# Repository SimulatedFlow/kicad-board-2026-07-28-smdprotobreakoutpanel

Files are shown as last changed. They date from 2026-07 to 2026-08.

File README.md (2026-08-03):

# 2026-07-28-smdprotobreakoutpanel

<!-- SF-STORE-BLOCK:BEGIN -->
## 🛒 Source-available — see before you buy

This repository contains the **full design files** of a commercial hardware board. It is **source-available, not open source**: read it, evaluate it, then buy a license to use it. See **LICENSE.md (source-available, purchase required)**.

**Get it / Buy:**
- eBay store — all our boards and PCB art: https://www.ebay.de/usr/simula-9
- Merch shop (dev & gaming): https://simulatedflow.myspreadshop.de
- Merch shop (Synthetica / EDM): https://synthetica.myspreadshop.de
- Direct / invoice (Simulated Flow UG): simulatedflow@gmail.com

_This board has no eBay item number of its own listed here — the store link above holds all current listings._

### 📬 **Free Board Documentation & Firmware Pack**

Schematics, BOMs and example-firmware docs for our STM32 carrier boards. Get it by joining the newsletter — plus a heads-up when something new ships. Double opt-in, unsubscribe in one click, no address sharing.

👉 **[Get the free pack](https://simulatedflow.teufel-engineering.com/newsletter/hardware/?q=gh)**

_© 2026 Simulated Flow UG. All rights reserved._
<!-- SF-STORE-BLOCK:END -->

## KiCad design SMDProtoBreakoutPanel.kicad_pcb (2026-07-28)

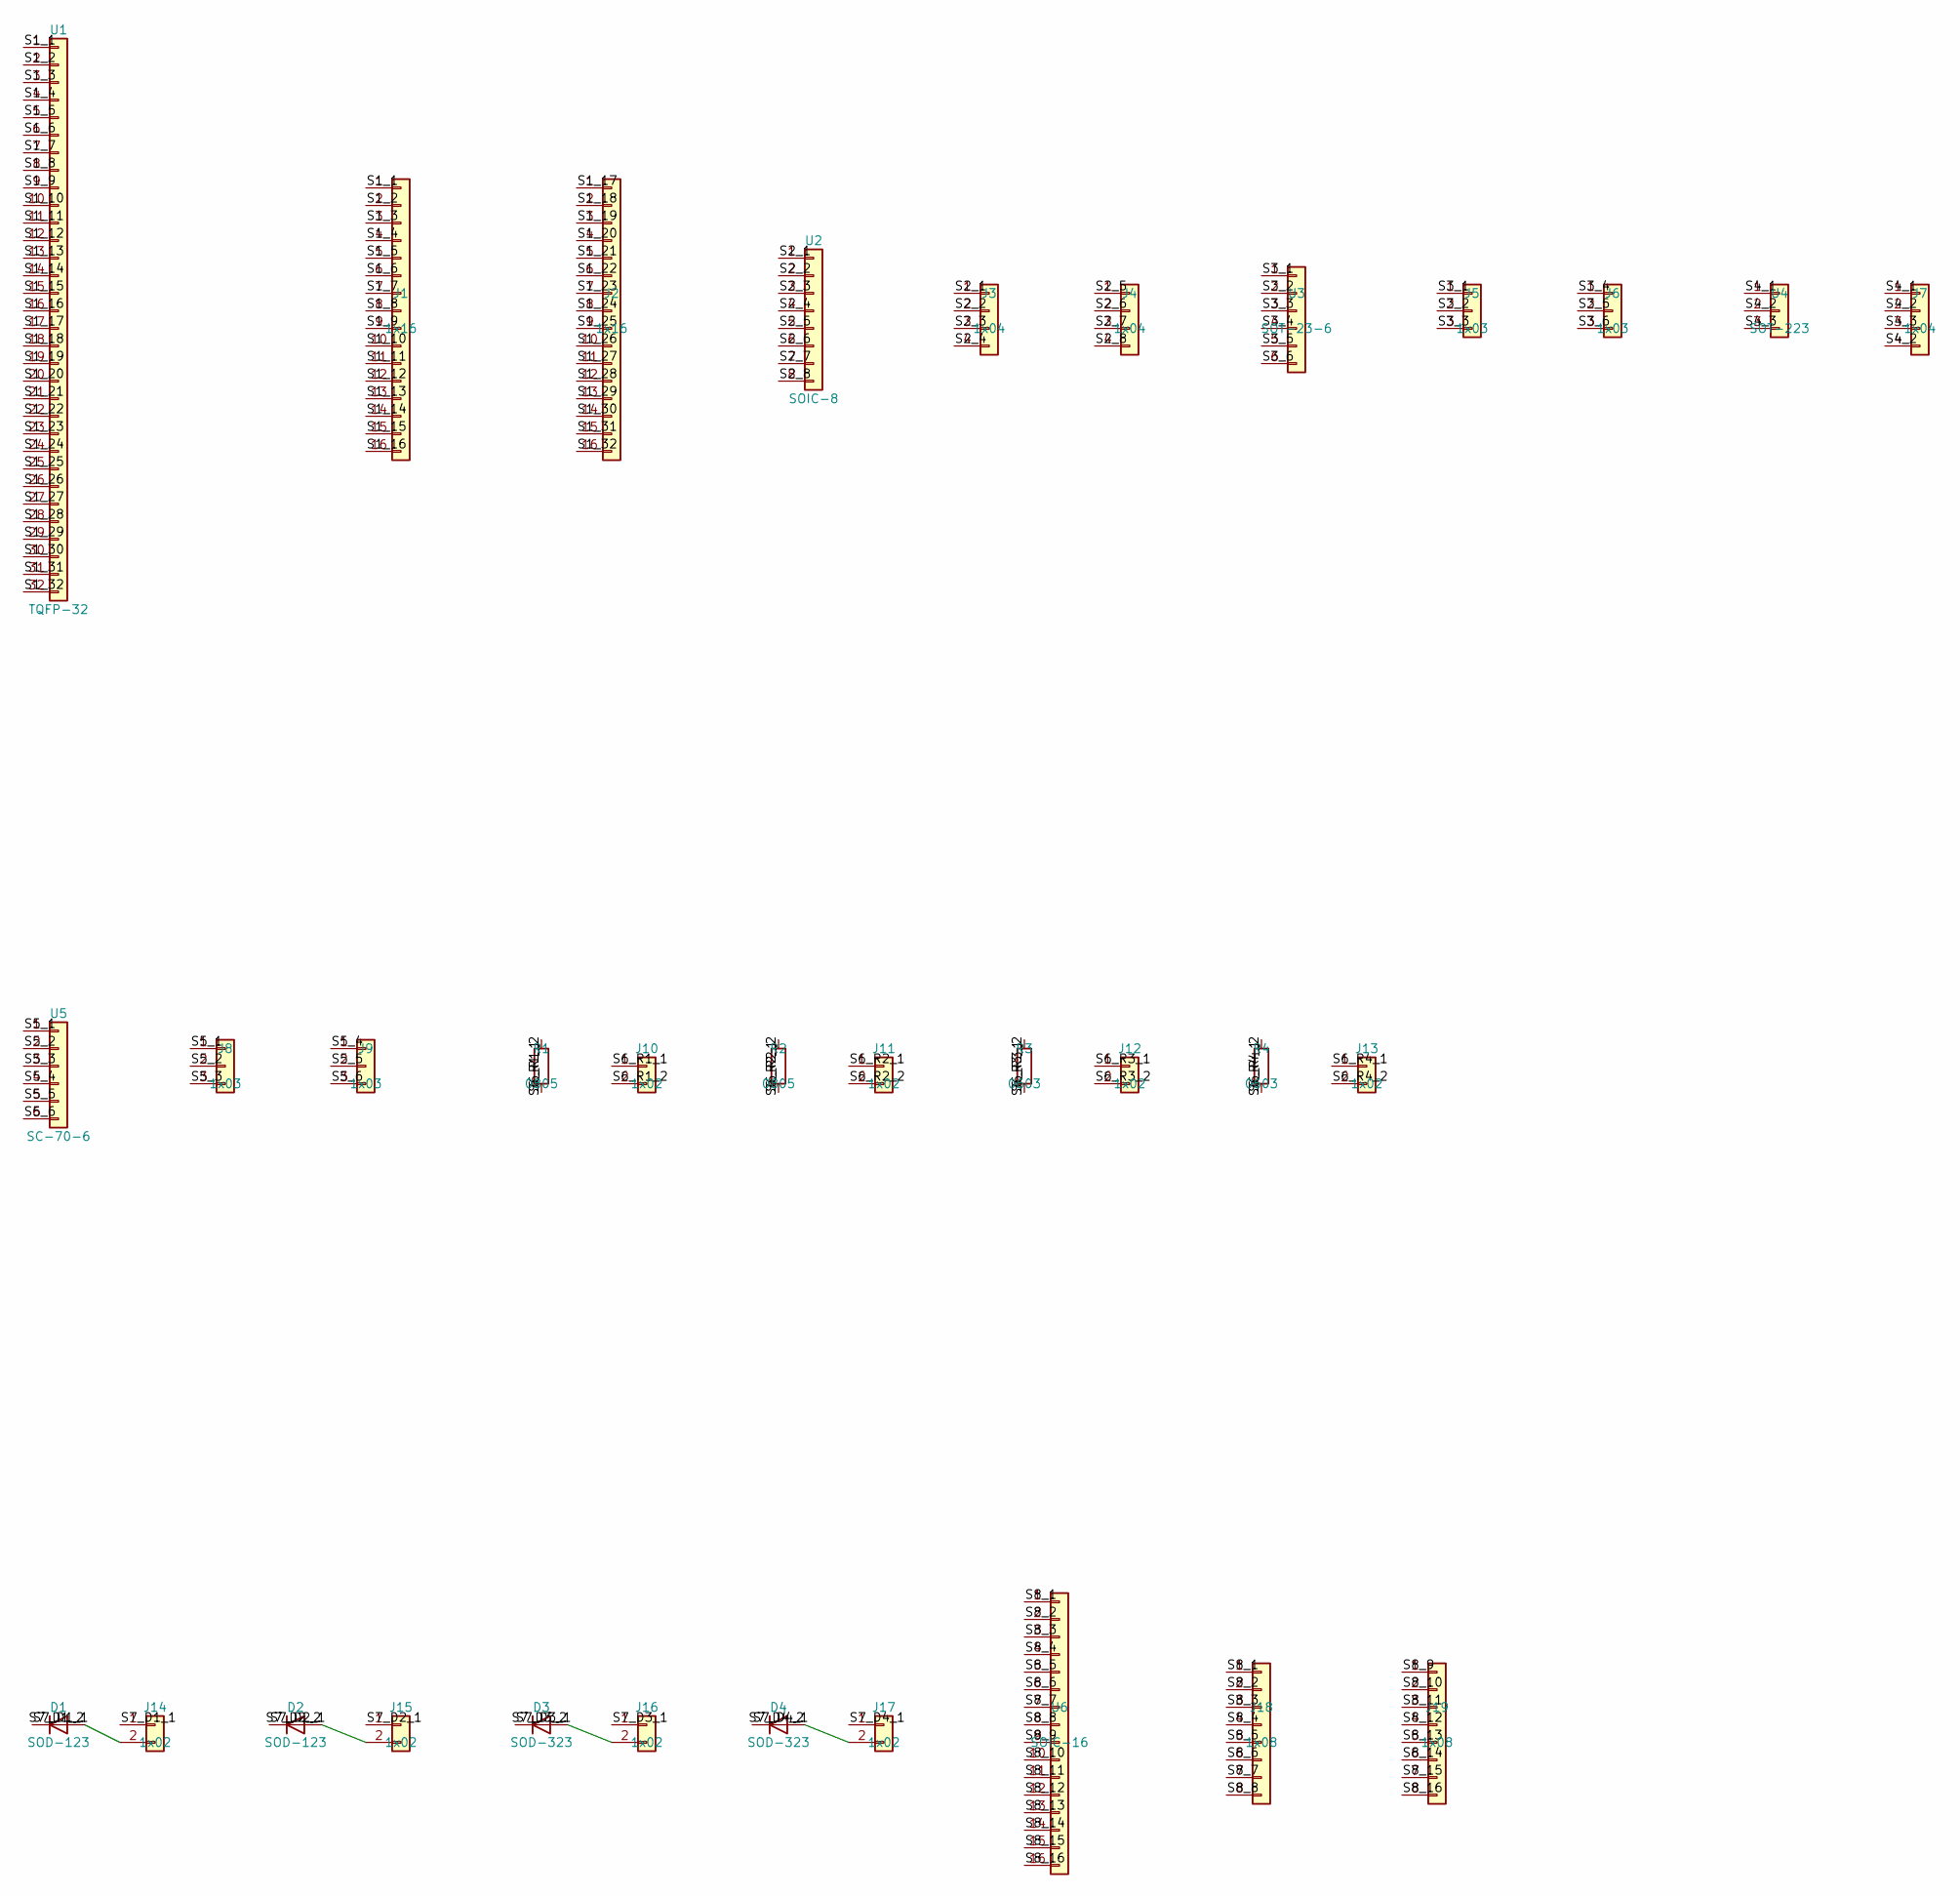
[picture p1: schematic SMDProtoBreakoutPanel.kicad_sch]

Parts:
D1, D2: SOD-123; D_SOD-123
D3, D4: SOD-323; D_SOD-323_HandSoldering
J1, J2: 1x16; PinHeader_1x16_P2.54mm_Vertical
J3, J4, J7: 1x04; PinHeader_1x04_P2.54mm_Vertical
J5, J6, J8, J9: 1x03; PinHeader_1x03_P2.54mm_Vertical
J10, J11, J12, J13, J14, J15, J16, J17: 1x02; PinHeader_1x02_P2.54mm_Vertical
J18, J19: 1x08; PinHeader_1x08_P2.54mm_Vertical
R1, R2: 0805; R_0805_2012Metric_Pad1.20x1.40mm_HandSolder
R3, R4: 0603; R_0603_1608Metric_Pad0.98x0.95mm_HandSolder
U1: TQFP-32; TQFP-32_7x7mm_P0.8mm
U2: SOIC-8; SOIC-8_3.9x4.9mm_P1.27mm
U3: SOT-23-6; SOT-23-6_Handsoldering
U4: SOT-223; SOT-223-3_TabPin2
U5: SC-70-6; SOT-363_SC-70-6
U6: SOIC-16; SOIC-16_3.9x9.9mm_P1.27mm

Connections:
S1_1: J1.1, U1.1
S1_2: J1.2, U1.2
S1_3: J1.3, U1.3
S1_4: J1.4, U1.4
S1_5: J1.5, U1.5
S1_6: J1.6, U1.6
S1_7: J1.7, U1.7
S1_8: J1.8, U1.8
S1_9: J1.9, U1.9
S1_10: J1.10, U1.10
S1_11: J1.11, U1.11
S1_12: J1.12, U1.12
S1_13: J1.13, U1.13
S1_14: J1.14, U1.14
S1_15: J1.15, U1.15
S1_16: J1.16, U1.16
S1_17: J2.1, U1.17
S1_18: J2.2, U1.18
S1_19: J2.3, U1.19
S1_20: J2.4, U1.20
S1_21: J2.5, U1.21
S1_22: J2.6, U1.22
S1_23: J2.7, U1.23
S1_24: J2.8, U1.24
S1_25: J2.9, U1.25
S1_26: J2.10, U1.26
S1_27: J2.11, U1.27
S1_28: J2.12, U1.28
S1_29: J2.13, U1.29
S1_30: J2.14, U1.30
S1_31: J2.15, U1.31
S1_32: J2.16, U1.32
S2_1: J3.1, U2.1
S2_2: J3.2, U2.2
S2_3: J3.3, U2.3
S2_4: J3.4, U2.4
S2_5: J4.1, U2.5
S2_6: J4.2, U2.6
S2_7: J4.3, U2.7
S2_8: J4.4, U2.8
S3_1: J5.1, U3.1
S3_2: J5.2, U3.2
S3_3: J5.3, U3.3
S3_4: J6.1, U3.4
S3_5: J6.2, U3.5
S3_6: J6.3, U3.6
S4_1: J7.1, U4.1
S4_2: J7.2, J7.4, U4.2
S4_3: J7.3, U4.3
S5_1: J8.1, U5.1
S5_2: J8.2, U5.2
S5_3: J8.3, U5.3
S5_4: J9.1, U5.4
S5_5: J9.2, U5.5
S5_6: J9.3, U5.6
S6_R1_1: J10.1, R1.1
S6_R1_2: J10.2, R1.2
S6_R2_1: J11.1, R2.1
S6_R2_2: J11.2, R2.2
S6_R3_1: J12.1, R3.1
S6_R3_2: J12.2, R3.2
S6_R4_1: J13.1, R4.1
S6_R4_2: J13.2, R4.2
S7_D1_1: D1.1 (K), J14.1
S7_D1_2: D1.2 (A), J14.2
S7_D2_1: D2.1 (K), J15.1
S7_D2_2: D2.2 (A), J15.2
S7_D3_1: D3.1 (K), J16.1
S7_D3_2: D3.2 (A), J16.2
S7_D4_1: D4.1 (K), J17.1
S7_D4_2: D4.2 (A), J17.2
S8_1: J18.1, U6.1
S8_2: J18.2, U6.2
S8_3: J18.3, U6.3
S8_4: J18.4, U6.4
S8_5: J18.5, U6.5
S8_6: J18.6, U6.6
S8_7: J18.7, U6.7
S8_8: J18.8, U6.8
S8_9: J19.1, U6.9
S8_10: J19.2, U6.10
S8_11: J19.3, U6.11
S8_12: J19.4, U6.12
S8_13: J19.5, U6.13
S8_14: J19.6, U6.14
S8_15: J19.7, U6.15
S8_16: J19.8, U6.16

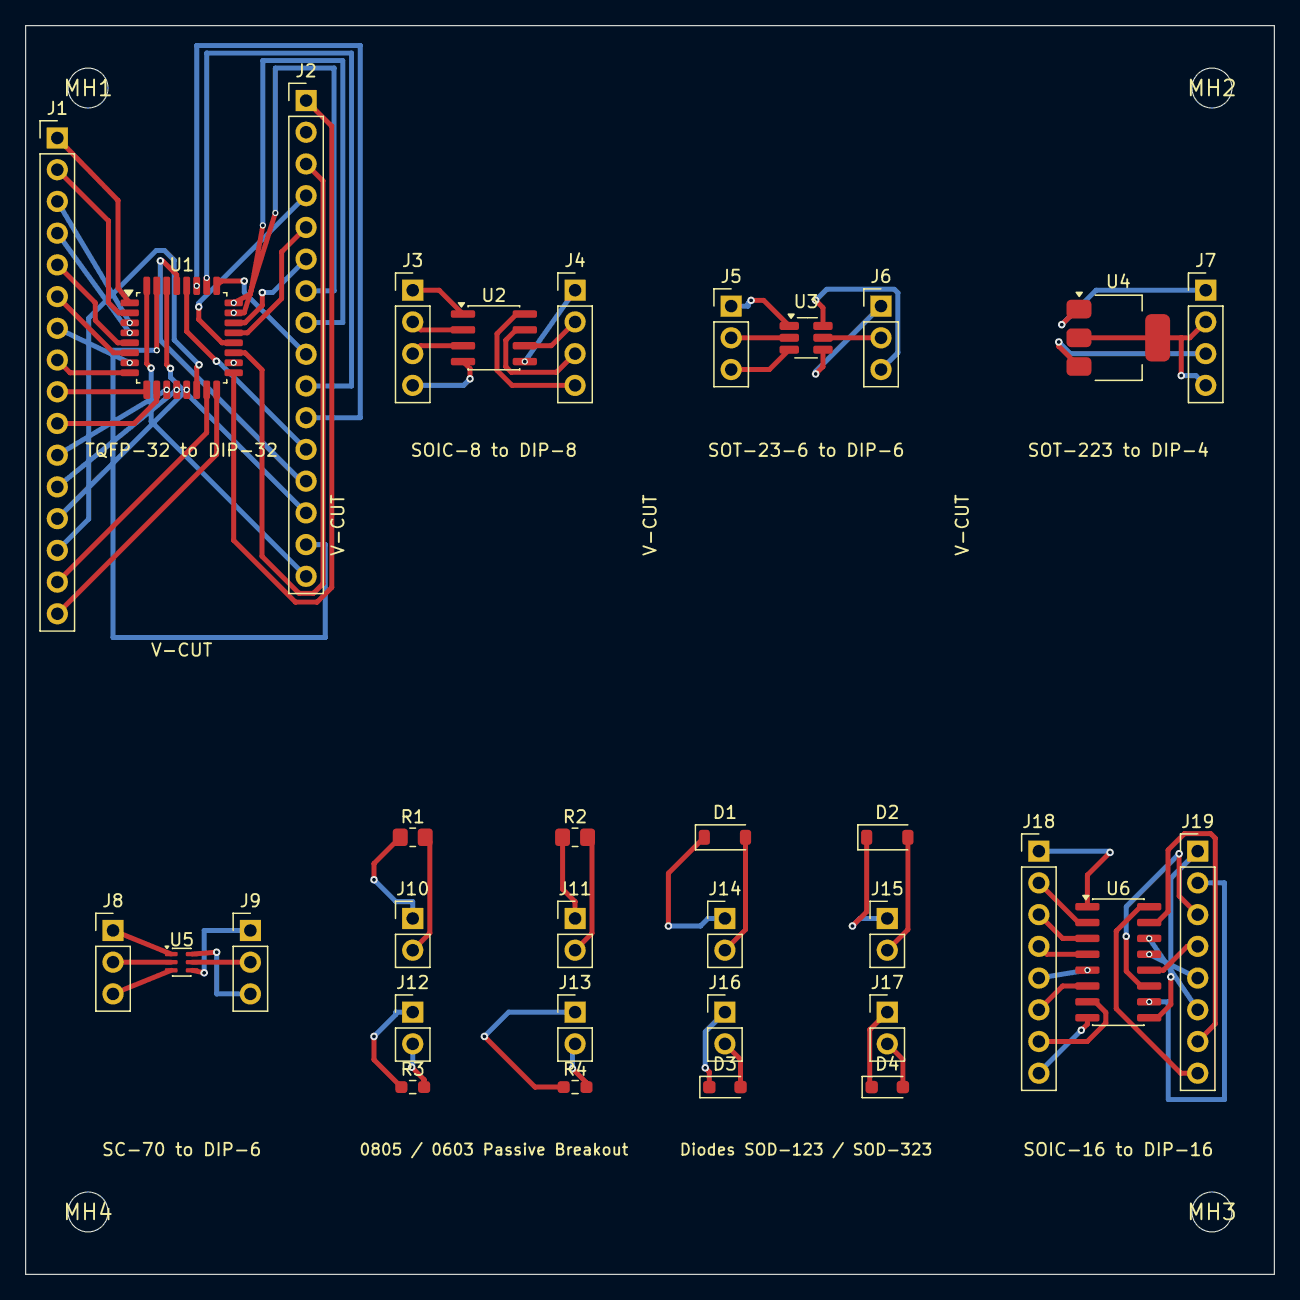
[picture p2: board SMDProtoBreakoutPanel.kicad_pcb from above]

Board: 4 copper layers, 100.0 x 100.0 mm, 37 parts (0 on the bottom side), 87 nets.

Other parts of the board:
MH1, MH2, MH3, MH4: MountingHole_3.2mm

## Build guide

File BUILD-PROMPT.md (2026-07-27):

```json
{
  "board_name": "SMDProtoBreakoutPanel",
  "one_liner": "Ein universelles, per V-Cut ausbrechbares SMD-zu-THT Adapterpanel für 8 gängige SMD-Footprints auf 2,54mm-Breadboard-Raster.",
  "market_gap": "Bastler scheuen oft SMD-Bauteile wegen der schwierigen Prototypisierung auf Breadboards. Dieses günstige, kombinierte All-in-One-Panel löst das Problem elegant und kostengünstig.",
  "confidence": "high",
  "price_eur": 12,
  "target_enclosure": "Keines (Direkte Breadboard-Nutzung / 100x100mm Panel)",
  "injection_notes": "keine"
}
```

## BUILD-PROMPT

### 1. Allgemeine Systemvorgaben (DFM & PCB-Eigenschaften)
- **Abmessungen:** Gesamt-Platine 100.0 mm × 100.0 mm. Vier Ecken bei (0,0), (100,0), (100,100), (0,100).
- **Lagen:** 4-Lagen-Standard-Stackup (F.Cu, In1.Cu, In2.Cu, B.Cu). Die internen Lagen `In1.Cu` (GND) und `In2.Cu` (VCC) werden als isolierte, segmentierte Shielding-Planes für jedes Segment ausgelegt (keine globale Verbindung, da alle Segmente elektrisch autark sind).
- **Leiterbahnen:** Signal-Clearance ≥ 0.3 mm, Bahnenbreite ≥ 0.4 mm.
- **V-Cut-Schnittlinien (Mausbisse/V-Scoring):**
  - Vertikale Score-Lines auf Layer `User.Drawings` (mit Silk-Text "V-CUT"):
    - X = 25.0 mm (von Y=0 bis Y=100)
    - X = 50.0 mm (von Y=0 bis Y=100)
    - X = 75.0 mm (von Y=0 bis Y=100)
  - Horizontale Score-Line auf Layer `User.Drawings`:
    - Y = 50.0 mm (von X=0 bis X=100)
  - *Dies teilt das Panel in exakt 8 identische Segmente von 25 mm × 50 mm.*
- **Montagelöcher:** 4× M3-Bohrungen (Durchmesser 3.2 mm, Pad-Durchmesser 6.0 mm) an den Ecken des Gesamtpanels:
  - Loch 1: (5.0, 5.0) mm
  - Loch 2: (95.0, 5.0) mm
  - Loch 3: (95.0, 95.0) mm
  - Loch 4: (5.0, 95.0) mm

---

### 2. Segment-Spezifikation (Schaltplan & Platzierung)

Jedes Segment ist elektrisch vollständig isoliert. Die Pins des SMD-Footprints werden 1:1 parallel auf die zugehörigen THT-Pinheader (RM 2.54 mm) herausgeführt, die an den Rändern des jeweiligen Segments platziert sind.

#### REIHE 1 (Y: 0.0 mm bis 50.0 mm)

- **Segment 1 (X: 0.0 bis 25.0 mm): TQFP-32 Adapter**
  - **SMD-Bauteil:** U1 (`Package_QFP:TQFP-32_7x7mm_P0.8mm`) platziert im Zentrum bei (12.5, 25.0).
  - **THT-Anschlüsse:** J1 & J2 (je `Connector_PinHeader_2.54mm:PinHeader_1x16_P2.54mm_Vertical`).
    - J1 platziert links bei X = 2.54 mm (Pins 1-16)
    - J2 platziert rechts bei X = 22.46 mm (Pins 17-32)
  - **Verbindung:** U1 Pins 1–16 zu J1 Pins 1–16; U1 Pins 17–32 zu J2 Pins 1–16.
  - **Silk-Beschriftung:** "TQFP-32 to DIP-32"

- **Segment 2 (X: 25.0 bis 50.0 mm): SOIC-8 Adapter**
  - **SMD-Bauteil:** U2 (`Package_SO:SOIC-8_3.9x4.9mm_P1.27mm`) bei (37.5, 25.0).
  - **THT-Anschlüsse:** J3 & J4 (je `Connector_PinHeader_2.54mm:PinHeader_1x04_P2.54mm_Vertical`).
    - J3 platziert links bei X = 33.68 mm (Pins 1-4)
    - J4 platziert rechts bei X = 41.32 mm (Pins 5-8)
  - **Verbindung:** U2 Pins 1–4 zu J3; U2 Pins 5–8 zu J4.
  - **Silk-Beschriftung:** "SOIC-8 to DIP-8"

- **Segment 3 (X: 50.0 bis 75.0 mm): SOT-23-6/5/3 Adapter**
  - **SMD-Bauteil:** U3 (`Package_TO_SOT_SMD:SOT-23-6_Handsoldering`) bei (62.5, 25.0).
  - **THT-Anschlüsse:** J5 & J6 (je `Connector_PinHeader_2.54mm:PinHeader_1x03_P2.54mm_Vertical`).
    - J5 links bei X = 58.68 mm, J6 rechts bei X = 66.32 mm.
  - **Verbindung:** U3 Pins 1–3 zu J5; U3 Pins 4–6 zu J6.
  - **Silk-Beschriftung:** "SOT-23-6 to DIP-6"

- **Segment 4 (X: 75.0 bis 100.0 mm): SOT-223 Adapter**
  - **SMD-Bauteil:** U4 (`Package_TO_SOT_SMD:SOT-223-3_TabPin2`) bei (87.5, 25.0).
  - **THT-Anschlüsse:** J7 (`Connector_PinHeader_2.54mm:PinHeader_1x04_P2.54mm_Vertical`) bei X = 93.0 mm.
  - **Verbindung:** U4 Pin 1 zu J7-1, Pin 2 (Tab) zu J7-2, Pin 3 zu J7-3, Pin 4 (Zusatz-Tab/Heatsink) zu J7-4.
  - **Silk-Beschriftung:** "SOT-223 to DIP-4"

---

#### REIHE 2 (Y: 50.0 mm bis 100.0 mm)

- **Segment 5 (X: 0.0 bis 25.0 mm): SC-70-6 Adapter**
  - **SMD-Bauteil:** U5 (`Package_TO_SOT_SMD:SOT-363_SC-70-6_Handsoldering`) bei (12.5, 75.0).
  - **THT-Anschlüsse:** J8 & J9 (je `Connector_PinHeader_2.54mm:PinHeader_1x03_P2.54mm_Vertical`).
    - J8 links bei X = 8.68 mm, J9 rechts bei X = 16.32 mm.
  - **Verbindung:** U5 Pins 1–3 zu J8; U5 Pins 4–6 zu J9.
  - **Silk-Beschriftung:** "SC-70 to DIP-6"

- **Segment 6 (X: 25.0 bis 50.0 mm): 0805 & 0603 Passives Breakout**
  - **SMD-Bauteile:** 
    - R1, R2 (`Resistor_SMD:R_0805_2012Metric_Pad1.15x1.40mm_HandSolder`) bei Y = 65.0 mm.
    - R3, R4 (`Resistor_SMD:R_0603_1608Metric_Pad1.05x0.95mm_HandSolder`) bei Y = 85.0 mm.
  - **THT-Anschlüsse:** Vier 2-Pin-Header J10, J11, J12, J13 (`Connector_PinHeader_2.54mm:PinHeader_1x02_P2.54mm_Vertical`).
  - **Verbindung:**
    - R1 Pins 1-2 an J10 Pins 1-2.
    - R2 Pins 1-2 an J11 Pins 1-2.
    - R3 Pins 1-2 an J12 Pins 1-2.
    - R4 Pins 1-2 an J13 Pins 1-2.
  - **Silk-Beschriftung:** "0805 / 0603 Passive Breakout"

- **Segment 7 (X: 50.0 bis 75.0 mm): SOD-123 & SOD-323 Dioden**
  - **SMD-Bauteile:**
    - D1, D2 (`Diode_SMD:D_SOD-123_HandSoldering`) bei Y = 65.0 mm.
    - D3, D4 (`Diode_SMD:D_SOD-323_HandSoldering`) bei Y = 85.0 mm.
  - **THT-Anschlüsse:** Vier 2-Pin-Header J14, J15, J16, J17 (`Connector_PinHeader_2.54mm:PinHeader_1x02_P2.54mm_Vertical`).
  - **Verbindung:**
    - D1 Anode/Kathode an J14.
    - D2 Anode/Kathode an J15.
    - D3 Anode/Kathode an J16.
    - D4 Anode/Kathode an J17.
  - **Silk-Beschriftung:** "Diodes SOD-123 / SOD-323" (Kathodenstrich auf Silk deutlich markieren!)

- **Segment 8 (X: 75.0 bis 100.0 mm): SOIC-16 Adapter**
  - **SMD-Bauteil:** U6 (`Package_SO:SOIC-16_3.9x9.9mm_P1.27mm`) bei (87.5, 75.0).
  - **THT-Anschlüsse:** J18 & J19 (je `Connector_PinHeader_2.54mm:PinHeader_1x08_P2.54mm_Vertical`).
    - J18 links bei X = 81.14 mm (Pins 1-8)
    - J19 rechts bei X = 93.86 mm (Pins 9-16)
  - **Verbindung:** U6 Pins 1–8 zu J18; U6 Pins 9–16 zu J19.
  - **Silk-Beschriftung:** "SOIC-16 to DIP-16"

---

### 3. Auszuführende Design-Schritte (KiCad-Automatisierungs-Pipeline)
1. **Projekt-Setup:** Lege ein neues KiCad-Projekt namens `SMDProtoBreakoutPanel` an.
2. **Schaltplan (Eeschema):** Erstelle die 8 isolierten Schaltplanabschnitte mit den oben definierten Bauteilen, Anschlüssen und Netzverbindungen.
3. **Platinen-Layout (Pcbnew):**
   - Definiere die Edge.Cuts als quadratischen Umriss von 100.0 mm × 100.0 mm.
   - Setze die 4 M3-Befestigungslöcher in die Ecken.
   - Platziere die SMD-Footprints und THT-Pinheader exakt innerhalb der 8 Segmentbereiche (jeweils 25×50 mm) laut Koordinatenvorgaben.
   - Zeichne die V-Cut-Trennlinien auf den Layer `User.Drawings`.
   - Bringe die Text-Schilder auf dem Silk-Layer (`F.SilkS`) an, sodass jedes Segment und jede Pinnummerierung gut ablesbar ist.
4. **Routing:**
   - Verbinde die Netze lokal auf den Segmenten. Da es sich um simple Punkt-zu-Punkt-Verbindungen handelt, ist dies extrem stabil autoroutbar.
   - Generiere Kupfer-Flächen für die Innenlagen als Schirmflächen (je Segment isoliert).
5. **DRC-Prüfung:** Führe den Design Rule Check (DRC) durch und behebe etwaige Fehler.
6. **Export:** Exportiere die Gerber-Dateien und Excellon-Bohrdateien strukturiert in das Verzeichnis `./gerbers`.

*Bitte fass am Ende des Prozesses kurz und ehrlich zusammen, was erfolgreich abgeschlossen wurde.*

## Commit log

2026-07-27 auto-backup 2026-07-28 00:26:45
    [SMDProtoBreakoutPanel.kicad_pcb]
2026-07-27 auto-backup 2026-07-28 01:26:33
    [SMDProtoBreakoutPanel.dsn, SMDProtoBreakoutPanel.kicad_pcb, SMDProtoBreakoutPanel.kicad_sch]
2026-07-28 auto-backup 2026-07-28 02:26:40
    [SMDProtoBreakoutPanel.kicad_pcb]
2026-07-28 auto-backup 2026-07-28 03:26:36
    [SMDProtoBreakoutPanel.dsn, SMDProtoBreakoutPanel.kicad_pcb]
2026-07-28 auto-backup 2026-07-28 04:26:37
    [SMDProtoBreakoutPanel.kicad_pcb]
